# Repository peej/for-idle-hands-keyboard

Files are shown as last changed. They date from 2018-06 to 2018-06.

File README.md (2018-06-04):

For Idle Hands is a 6x4x2 key ortholinear split keyboard PCB.

The goal of this project is to build a Let's Split keyboard clone from sub-100x100mm PCB boards.:

* Designed to be easy to build with minimal soldering experience.
* Switch plate cutouts in the PCB so the same PCB can also be used as a switch plate.
* Serial communication over a TRRS cable.
* Single sided PCB, so both halves of the keyboard are identical.

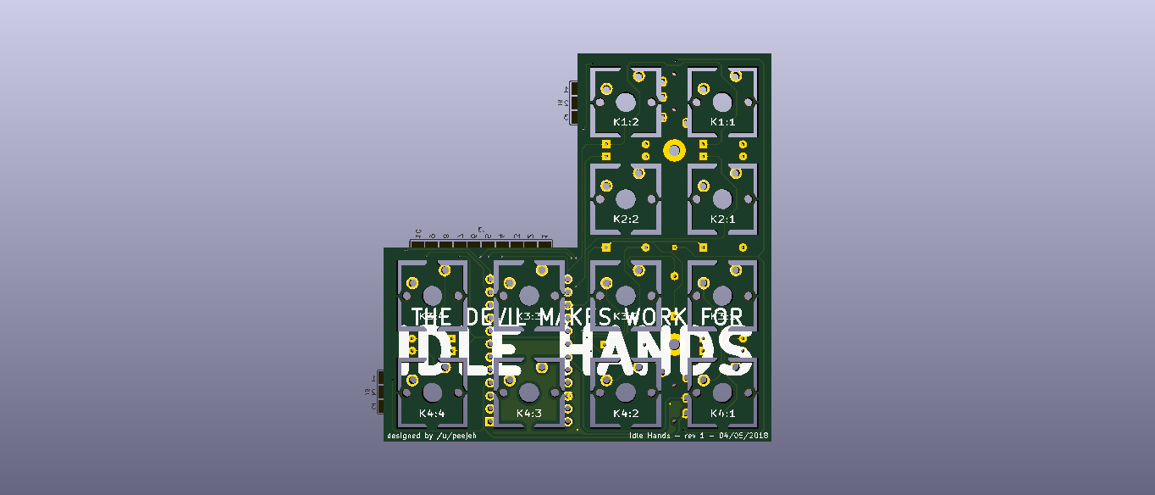
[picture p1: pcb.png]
PCB render


# Bill of Materials (BOM)

* 8 PCBs, 4 for components and 4 as switch plates.
* 48 MX compatible switches.
* 48 1n4148 diodes.
* 2 Pro Micro controllers with headers or DIP sockets.
* 2 PJ320A 3.5mm TRRS jacks.
* TRRS cable and micro USB cable.
* 8 2M standoffs (12mm, depending on required height)
* 16 2M screws
* 48 MX compatible key caps.

## Tools

* Hacksaw blade or similar
* Flat edged file or sanding paper
* Soldering iron and solder

# Ordering PCBs

PCBs can be manufactuered by a variety of online PCB fabricators. You can use [PCBShopper](https://pcbshopper.com/) to search for the best price.

The zip file in the gerber directory contains the gerber files your fabricator will need to make the PCB [for-idle-hands.zip](https://github.com/peej/for-split-keyboard/blob/master/gerber/for-idle-hands.zip) PCB.

When uploading the gerber zip files, use the default PCB settings. The plate PCB thickness should be 1.6mm for the switches to snap into the plate securely.

# Construction

* You will need 8 PCBs.
* If you are using the 6x4x2 layout, carefully cut the bottom row of switch footprints from the 4 PCBs.
* Use the hacksaw blade to remove the 4 support screw holes from the 2 component PCBs.
* Use a hacksaw blade to remove the cutouts for the switch plate PCBs.
* Solder the diodes onto the underside of each PCB.
* Solder on the Pro Micro headers (or a 24 pin DIP socket) onto the underside of each PCB, do not solder on the Pro Micros yet.
* Solder the PJ320A TRRS sockets onto the underside of each PCB.
  * There are 2 positions per board, use the right position on the left hand PCB and the left position on the right hand PCB.
  * Ensure that the pins will not foul the placement of the switches and still allow the switches to sit flat on the PCB.
  * You may need to slightly bend the pins inwards away from the switch footprint.
* Insert the switches into the plate and then into the top of the PCBs.
  * Insert all the switches and ensure that the pins of each switch are correctly coming through the board and are not bent under the PCB.
  * The top switch that sits underneath the Pro Micro can be inserted in either a north or south facing orientation. North facing helps to prevent it shorting on the Pro Micro components.
* Solder all the switch pins.
* Solder on the Pro Micros, ensure that you get them the correct way around, the chip side should be face down towards the PCB.
* Attach the standoffs to the plate PCB with the screws.
* Connect the halves together with the TRRS cable.
* Flash both Pro Micros with the firmware, see the [QMK documentation](http://qmk.fm/) on how to build and flash the firmware.

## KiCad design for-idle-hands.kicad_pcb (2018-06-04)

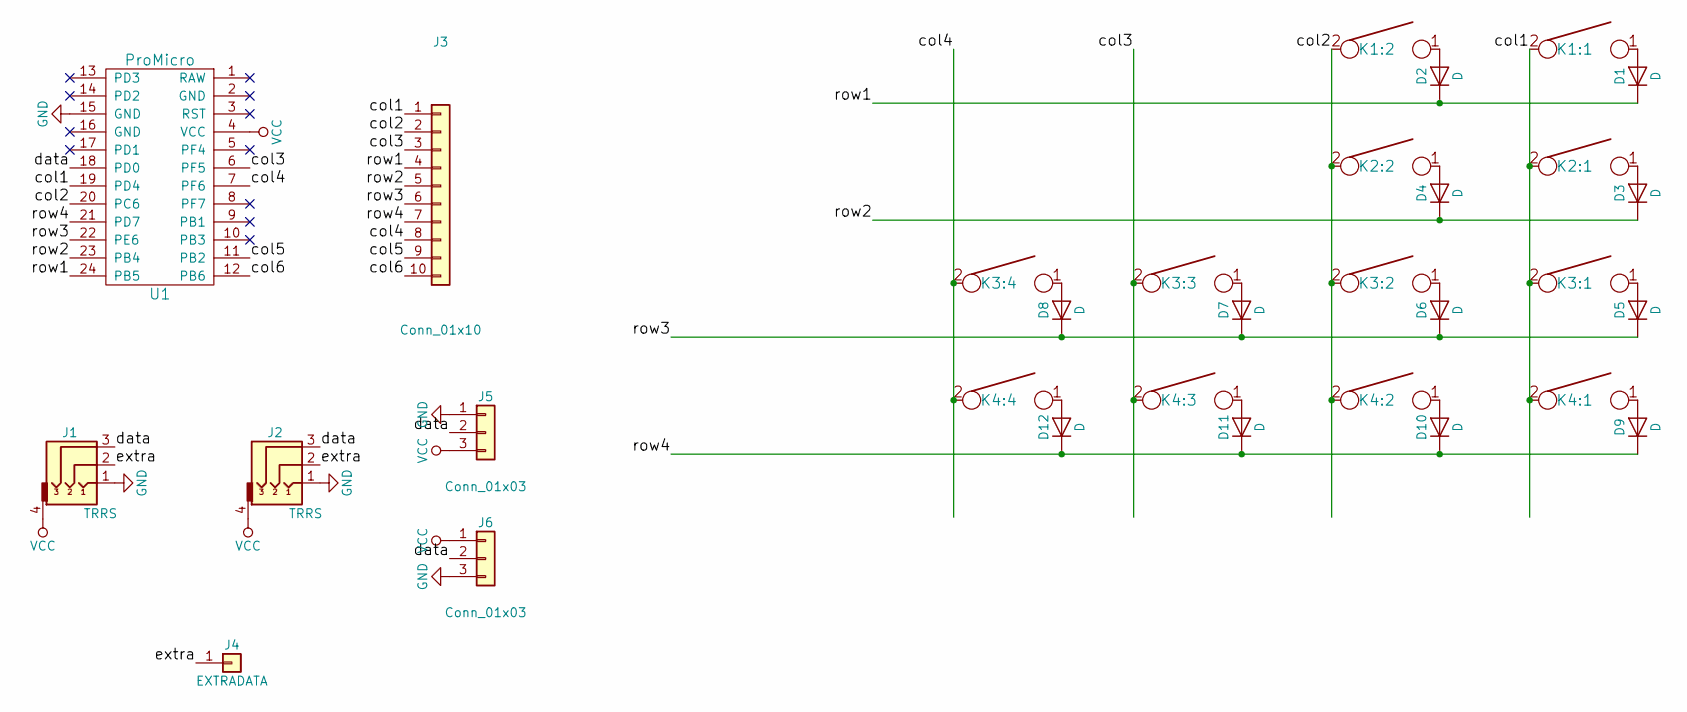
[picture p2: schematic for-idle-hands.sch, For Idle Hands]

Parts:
D1, D2, D3, D4, D5, D6, D7, D8, D9, D10, D11, D12: D; DIODE
J1, J2: TRRS; PJ-320A
J3: Conn_01x10; CONNECTOR_10
J4: EXTRADATA; Pin_Header_Straight_1x01_Pitch1.00mm
J5, J6: Conn_01x03; CONNECTOR_3
K1:1: K5; MX_CUTOUT
K1:2: K4; MX_CUTOUT
K2:1: K15; MX_CUTOUT
K2:2: K14; MX_CUTOUT
K3:1: K25; MX_CUTOUT
K3:2: K24; MX_CUTOUT
K3:3: K23; MX_CUTOUT
K3:4: K22; MX_CUTOUT
K4:1: K35; MX_CUTOUT
K4:2: K34; MX_CUTOUT
K4:3: K33; MX_CUTOUT
K4:4: K32; MX_CUTOUT
U1: ProMicro; Pro_Micro_ChipSideDown

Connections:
/col1: J3.1, K1:1.2, K2:1.2, K3:1.2, K4:1.2, U1.19 (PD4)
/col2: J3.2, K1:2.2, K2:2.2, K3:2.2, K4:2.2, U1.20 (PC6)
/col3: J3.3, K3:3.2, K4:3.2, U1.6 (PF5)
/col4: J3.8, K3:4.2, K4:4.2, U1.7 (PF6)
/col5: J3.9, U1.11 (PB2)
/col6: J3.10, U1.12 (PB6)
/data: J1.3, J2.3, J5.2, J6.2, U1.18 (PD0)
/extra: J1.2, J2.2, J4.1
/row1: D1.1 (K), D2.1 (K), J3.4, U1.24 (PB5)
/row2: D3.1 (K), D4.1 (K), J3.5, U1.23 (PB4)
/row3: D5.1 (K), D6.1 (K), D7.1 (K), D8.1 (K), J3.6, U1.22 (PE6)
/row4: D9.1 (K), D10.1 (K), D11.1 (K), D12.1 (K), J3.7, U1.21 (PD7)
GND: J1.1, J2.1, J5.1, J6.3, U1.15 (GND)
unnamed: D1.2 (A), K1:1.1
unnamed: D2.2 (A), K1:2.1
unnamed: D3.2 (A), K2:1.1
unnamed: D4.2 (A), K2:2.1
unnamed: D5.2 (A), K3:1.1
unnamed: D6.2 (A), K3:2.1
unnamed: D7.2 (A), K3:3.1
unnamed: D8.2 (A), K3:4.1
unnamed: D9.2 (A), K4:1.1
unnamed: D10.2 (A), K4:2.1
unnamed: D11.2 (A), K4:3.1
unnamed: D12.2 (A), K4:4.1
VCC: J1.4, J2.4, J5.3, J6.1, U1.4 (VCC)

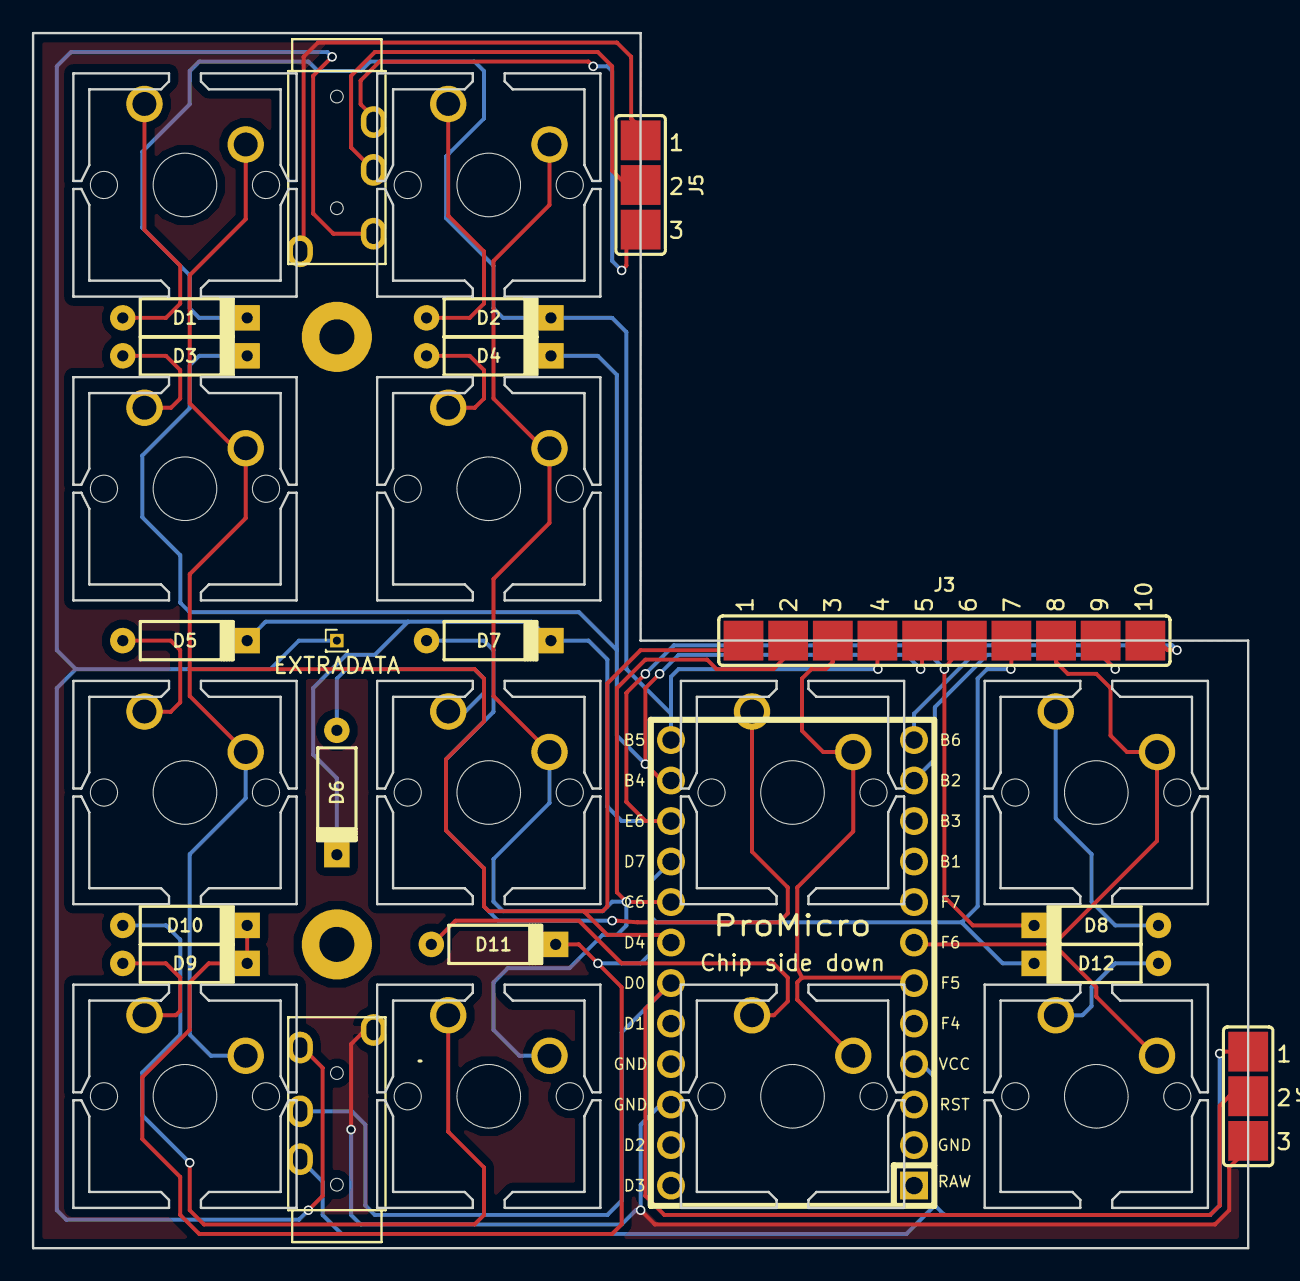
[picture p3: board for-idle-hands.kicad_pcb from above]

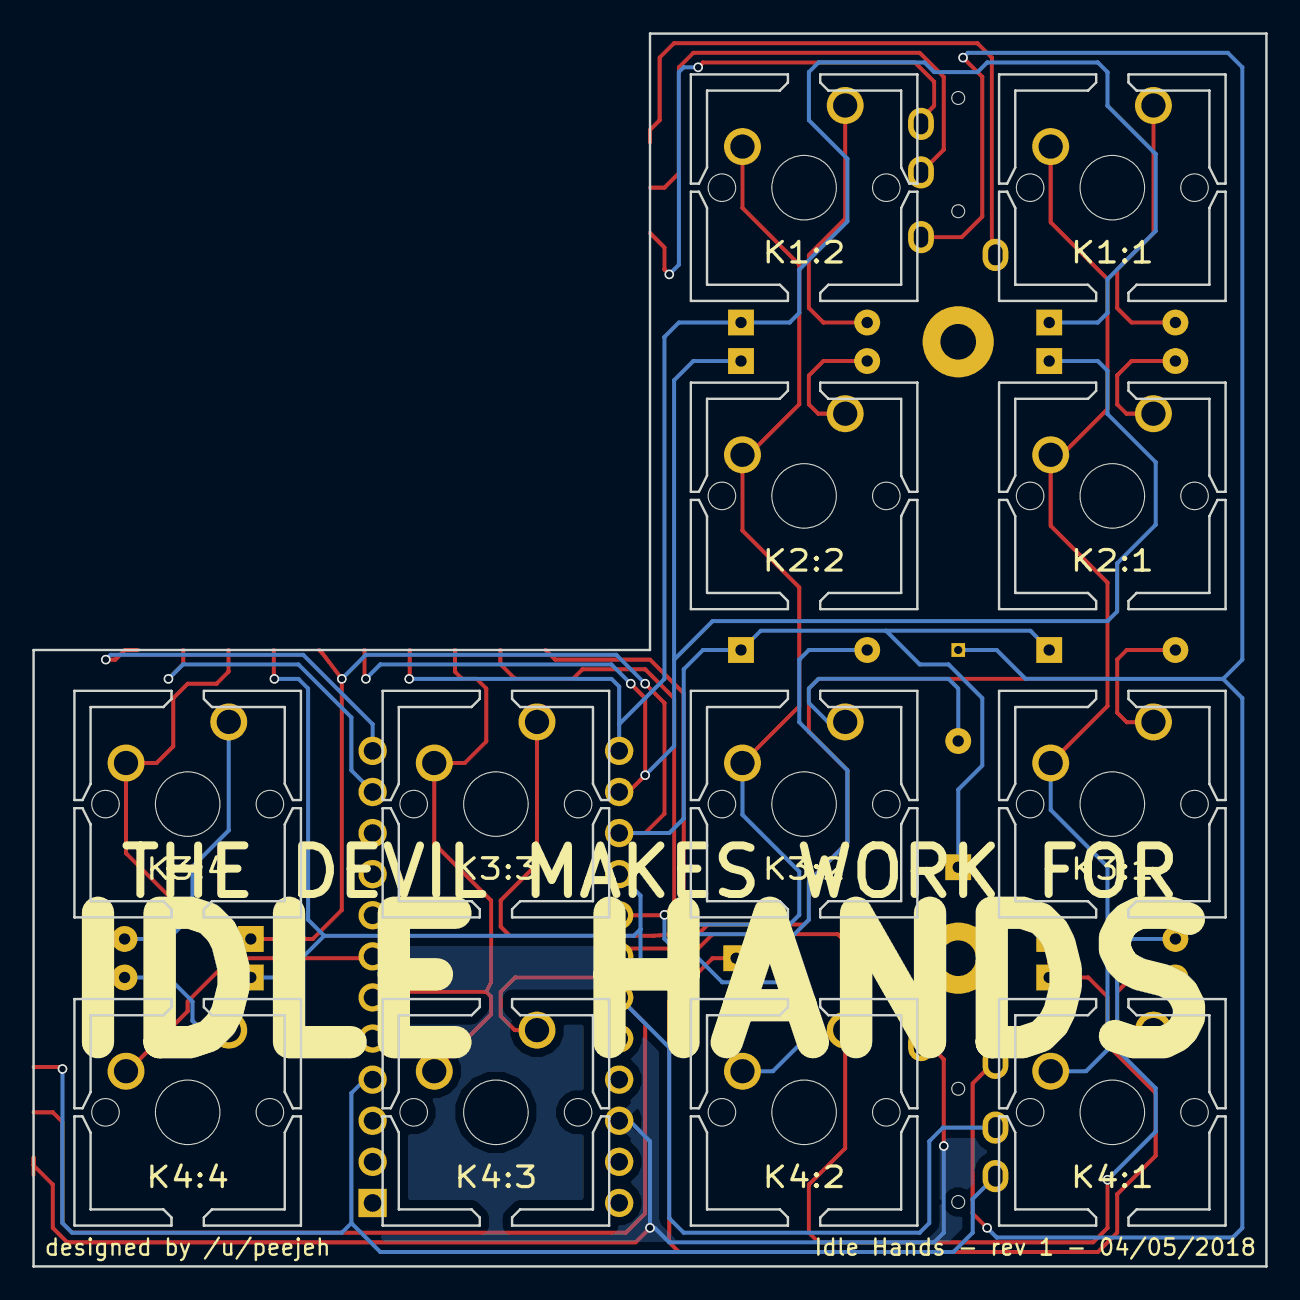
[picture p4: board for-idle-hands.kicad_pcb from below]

Board: 2 copper layers, 76.2 x 76.2 mm, 31 parts (12 on the bottom side), 26 nets.

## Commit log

2018-06-04 Add footprints
2018-06-04 Add schematic and PCB design
    [for-idle-hands.kicad_pcb, for-idle-hands.sch]
